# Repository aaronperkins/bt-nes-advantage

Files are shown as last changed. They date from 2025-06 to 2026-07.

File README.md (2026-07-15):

# Bluetooth NES Advantage

> ⚠️ **This repository is obsolete (v1).** The Bluetooth NES Advantage has been fully redesigned. See the current **v2** repository for the latest hardware, firmware, and docs: **https://github.com/cajunpanda/bluetooth-nes-advantage**

Integrated Bluetooth adapter for the NES Advantage (NES-026)

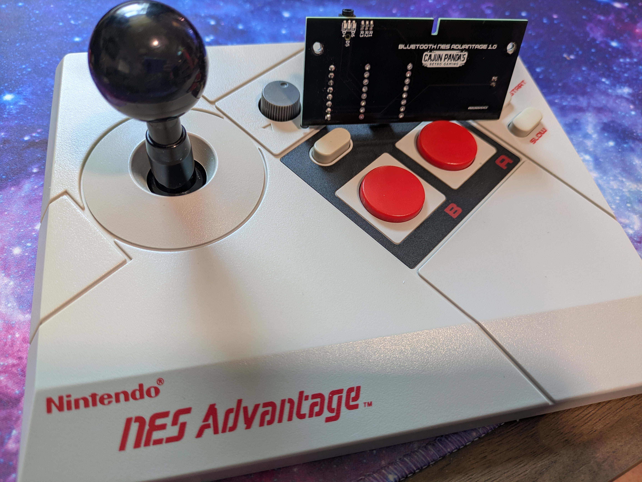
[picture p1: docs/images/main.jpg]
BT-NES-Advantage Hero Shot


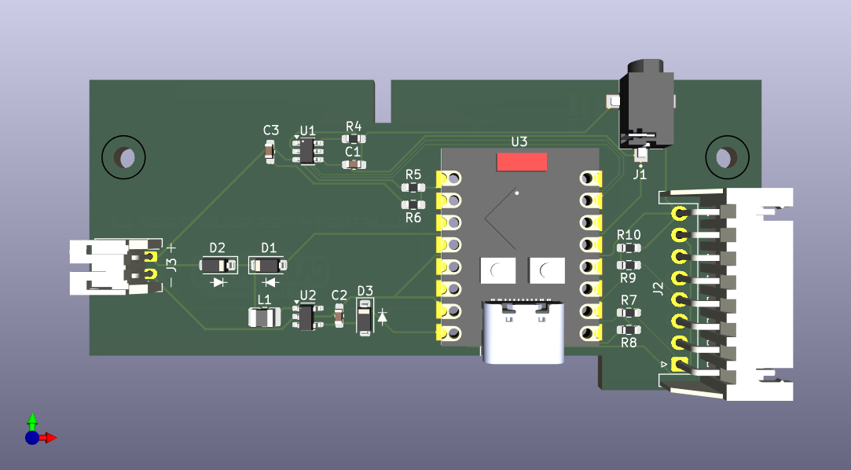
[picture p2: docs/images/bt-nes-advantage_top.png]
PCB Top


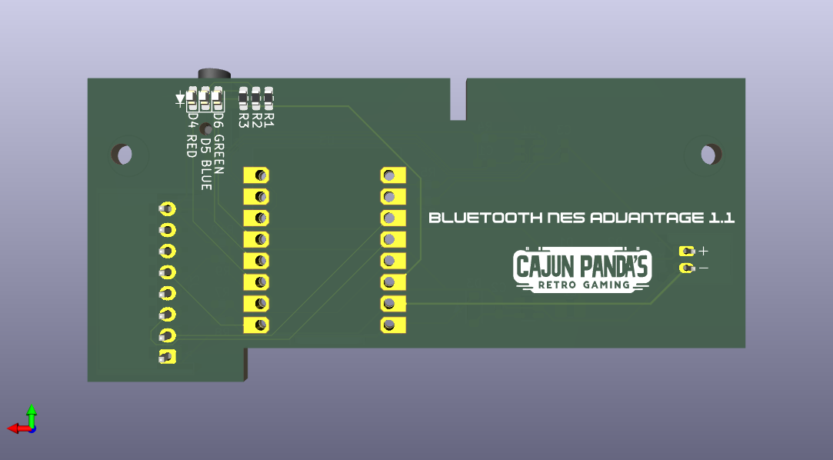
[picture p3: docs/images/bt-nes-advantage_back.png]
PCB Back


## Where to buy
Buy a completed kit ready to drop into your NES Advantage here:

[Tindie](https://www.tindie.com/products/cajunpanda/bluetooth-nes-advantage-kit/)

[Ko-Fi](https://ko-fi.com/s/c1f66f6bd5)

## Support
[Discord](https://discord.gg/t8uT8NgTnc)

## Overview
The BT-NES-Advantage is a custom Bluetooth adapter built into the NES Advantage controller, allowing it to connect wirelessly to modern devices as a standard Bluetooth gamepad. This project uses an ESP32-C3 microcontroller to read the NES controller's inputs and transmit them via Bluetooth HID protocol.

## Features
- Wireless Bluetooth LE connectivity
- Turbo and slow motion functions work as normal
- Player select switch
   - Exposes two game input devices for player 1 and 2. The player select switch redirects output to one or the other.
- Standard gamepad HID implementation, tested with:
   - BlueRetro (only works with player 1 switch)
   - Windows
   - Android
   - SteamOS
   - Linux
- *This mod does not work with the 8BitDo Retro Receiver, it doesn't support BLE*
- Long battery life with low power sleep mode
- RGB status LED indication
- Battery level monitoring and reporting
- 5V DC barrel jack charging port

## Usage Instructions

### Pairing the Controller
1. **Turn on the controller** - The controller will automatically wake up when the Start button is held.
2. **Enter pairing mode** - The controller will automatically enter pairing mode when turned on, indicated by a blinking blue LED.
3. **Pair with your device** - On your device (computer, smartphone, game console, etc.), go to Bluetooth settings and select "NES Advantage" from the list of available devices.
4. **Connection successful** - When successfully connected, the blue LED will turn solid.

### Button Mapping
The NES Advantage controller buttons are mapped to standard gamepad controls:
- **D-Pad** - Maps to the directional pad or left analog stick (configurable)
- **A button** - Maps to Button 1 (default profile) or Button 1 (Blue Retro profile)
- **B button** - Maps to Button 2 (default profile) or Button 4 (Blue Retro profile)
- **Start button** - Maps to Start button (Button 12)
- **Select button** - Maps to Select button (Button 11)

#### Button Mapping Profiles
The controller supports multiple button mapping profiles:
1. **Default Profile** - A=Button 1, B=Button 2, Select=Button 11, Start=Button 12
2. **Blue Retro Profile** - A=Button 1, B=Button 4, Select=Button 11, Start=Button 12

To change profiles, hold **A + B + Up** for 5 seconds. The red LED will blink to indicate the current profile (1 blink = Profile 1, 2 blinks = Profile 2).

#### Directional Input Modes
The controller supports three directional input modes:
1. **D-Pad Only** - Directional input sent only to the D-pad/hat switch
2. **Axes Only** - Directional input sent only to the analog stick axes
3. **Both** - Directional input sent to both D-pad and analog stick axes

To change directional modes, hold **Down + A + B** for 5 seconds. The red LED will blink to indicate the current mode (1 blink = D-Pad Only, 2 blinks = Axes Only, 3 blinks = Both).

### Special Functions
- **Sleep mode** - To manually put the controller into sleep mode, hold the **Start button** for 5 seconds. The LEDs will turn off when the controller enters sleep mode.
- **Reconnect/Pair new device** - To disconnect from the current device and enter pairing mode again, hold the **Select button** for 5 seconds.
- **Wake from sleep** - Hold the **Start button** to wake the controller from sleep mode.
- **Change button mapping profile** - Hold **A + B + Up** for 5 seconds to cycle through available button mapping profiles. The red LED will blink to indicate the current profile number.
- **Change directional pad mode** - Hold **Down + A + B** for 5 seconds to cycle through directional input modes (D-Pad Only, Axes Only, Both). The red LED will blink to indicate the current mode.

### LED Indicators
- **Blue LED**:
  - Solid ON - Connected to a device
  - Blinking - In pairing mode (advertising)
  - OFF - Not connected or in sleep mode
- **Green LED**:
  - Blinking - Battery charging
  - Solid ON - Battery fully charged
  - OFF - Not charging
- **Red LED**:
  - Blinking - Low battery (below 20%)
  - OFF - Battery level normal

### Battery and Power
- The controller uses a rechargeable LiPo battery.
- To charge, connect a 5V DC power adapter to the barrel jack.
- Battery level is reported to the connected device when supported.
- The controller will automatically enter sleep mode after 5 minutes of inactivity to conserve power.
- When advertising (pairing mode), the controller will stop advertising after 30 seconds to save battery.

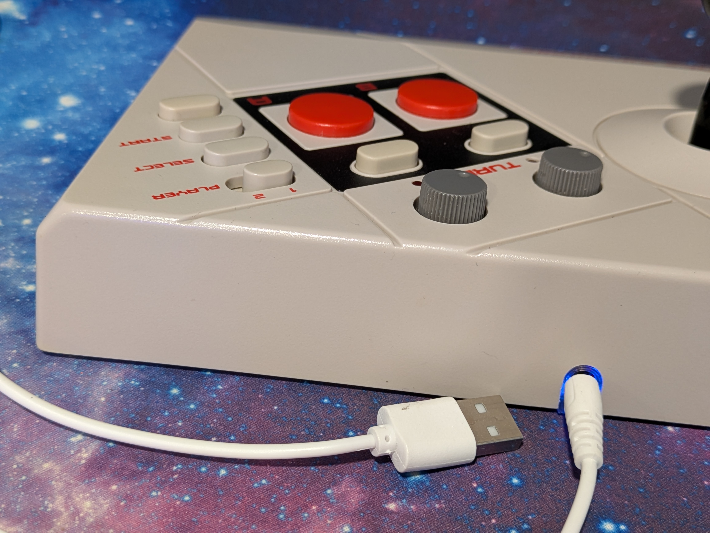
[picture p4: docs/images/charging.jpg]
Controller Charging

*NES Advantage controller charging via 5V DC barrel jack*

### 3D Printable DC Jack Plug

For a clean installation, a custom 3D printable DC jack plug is available that fits perfectly in the NES Advantage case:

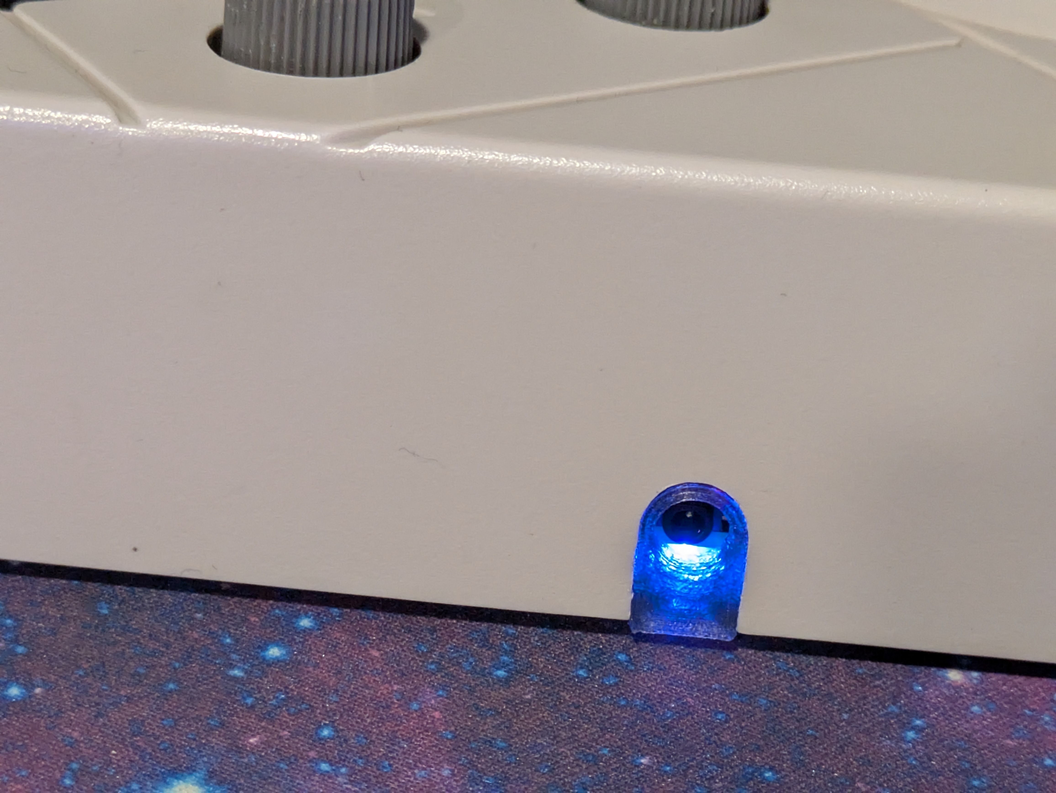
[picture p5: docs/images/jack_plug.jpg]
DC Jack Plug

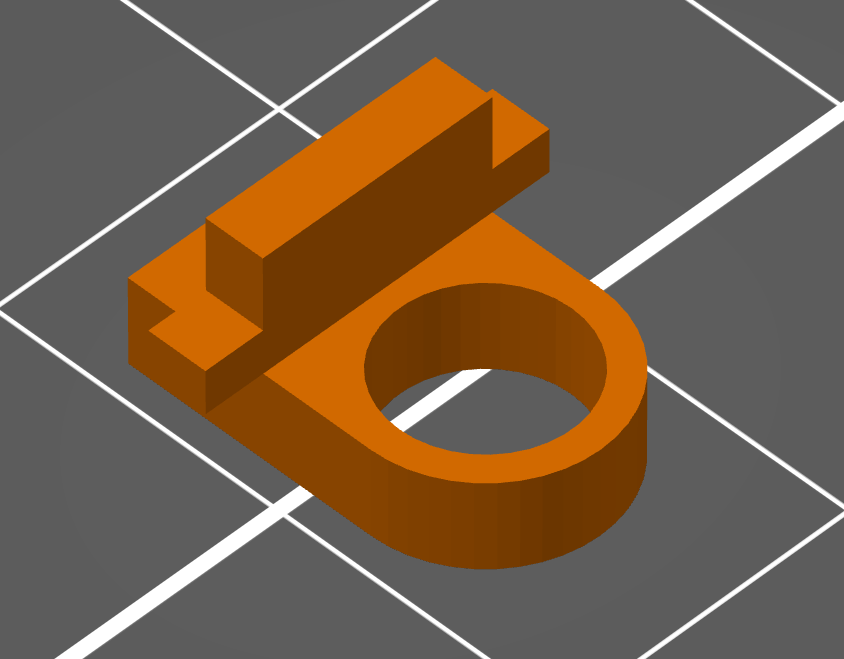
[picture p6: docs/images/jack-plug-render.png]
DC Jack Plug Render


**Download STL file**: [bt_nes_advantage-jack_plug.stl](models/bt_nes_advantage-jack_plug.stl)

Print with a transparent PLA in order to see the status LEDs.

### Troubleshooting
- If unable to pair with a new device, ensure the controller is in pairing mode (blue LED blinking).

## Technical Specifications
- MCU: ESP32-C3 (LOLIN C3 Mini)
- Bluetooth: BLE 5.0
- Battery: 3.7V LiPo 
- Charging: Via 5V DC barrel jack
- Power consumption: ~120mA when connected, <1mA in sleep mode
- Original NES controller compatibility: 100% hardware compatible

## PCB Assembly Instructions
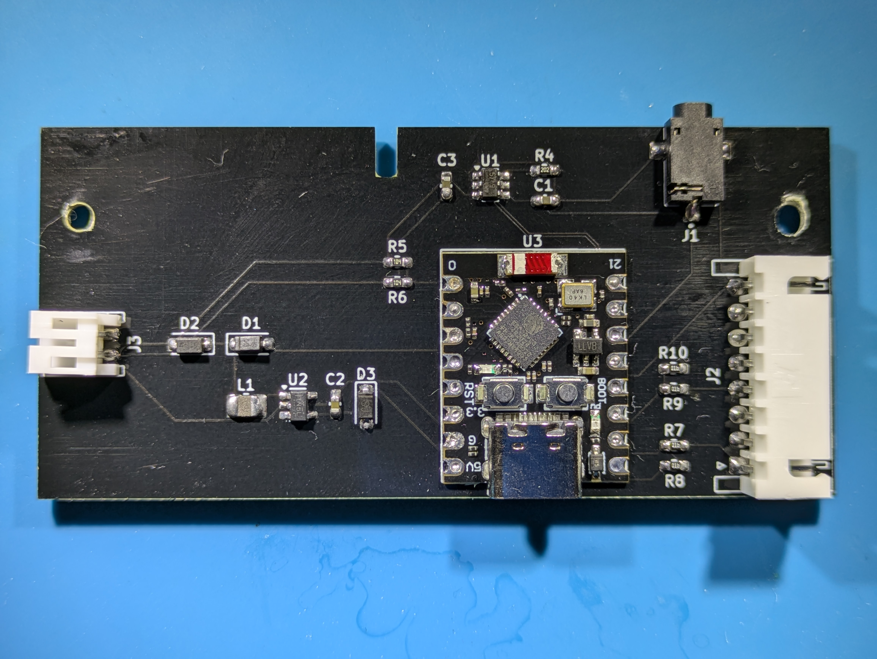
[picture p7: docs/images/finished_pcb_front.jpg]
Finished PCB

### Bill of Materials (BOM)

| Designator | Qty | Value | Footprint | Description | Notes |
|---|-----|---|---|---|---|
| C1, C3 | 2 | 10µF | C_0603_1608Metric | Unpolarized capacitor | SMT |
| C2 | 1 | 22µF | C_0603_1608Metric | Unpolarized capacitor | SMT |
| D1, D2, D3 | 3 | 1N5817W | D_SOD-123 | Schottky diode | SMT |
| D4, D5, D6 | 3 | LED | LED_0603_1608Metric | RGB LED (R,G,B) | SMT, 1=K 2=A |
| J1 | 1 | PJ-043-SMT-TR | CUI_PJ-040-SMT-TR | DC Power Jack | SMT, 5V input |
| J2 | 1 | Conn_01x08_Socket | JST_XH_S8B-XH-A_1x08_P2.50mm | 8-pin NES controller connector | Horizontal, THT |
| J3 | 1 | JST Connector | JST_PH_S2B-PH-K_1x02_P2.00mm | LiPo battery connector | Horizontal, THT |
| L1 | 1 | 2.2µH | L_1008_2520Metric | Inductor | SMT |
| R1, R2, R3 | 3 | 200Ω | R_0603_1608Metric | Resistor for LEDs | SMT |
| R7, R8, R9, R10 | 4 | 1KΩ | R_0603_1608Metric | Resistor | SMT |
| R4 | 1 | 2KΩ | R_0603_1608Metric | Resistor | SMT |
| R5, R6 | 2 | 100KΩ | R_0603_1608Metric | Voltage divider for battery monitoring | SMT |
| U1 | 1 | TP4057 | TSOT-23-6 | Li-ion battery charger IC | SMT |
| U2 | 1 | TPS613222ADBV | SOT-23-5 | 5V boost converter | SMT |
| U3 | 1 | ESP32-C3_SUPERMINI_TH | ESP32-C3 SuperMini | ESP32-C3 WiFi/BLE module | THT |

### Parts Sourcing

- **PCB**: [PCBWay Project - Order PCB](https://www.pcbway.com/project/shareproject/Bluetooth_NES_Advantage_865d24ef.html)
- **Parts List**: [Digikey Parts List](https://www.digikey.com/en/mylists/list/EVZPX74W7P)
- **ESP32-C3 SuperMini Module**: [Amazon Link](https://a.co/d/1LoWyFs)
- **J2 Connector Harness Cable**: [Amazon Link](https://a.co/d/abYfjqw)
- **Recommended Battery**: [103450 3.7V LiPo Battery](https://a.co/d/7UFYwX9) (IMPORTANT: Check polarity before connecting)
- **Charging cable**: [DC 2.5x0.7mm Barrel Jack Power Cable](https://a.co/d/4bPUQj2)

### Schematic
[Link to PDF](docs/schematic.pdf)

### Gerber
[Link to Gerber files](pcb/bt-nes-advantage.kicad_pcb.zip)

### Assembly Steps
1. **PCB Preparation**
   - Ensure you have the latest PCB design files from the `pcb` directory
   - Verify that all components from the BOM are available before starting

2. **Component Placement Order**
   - Start with SMD components in this order:
     1. Resistors (R1-R10)
     2. Capacitors (C1-C3)
     3. Diodes (D1-D3)
     4. LEDs (D4-D6) - Note the polarity! Cathode (K) is marked
     5. ICs (U1, U2)
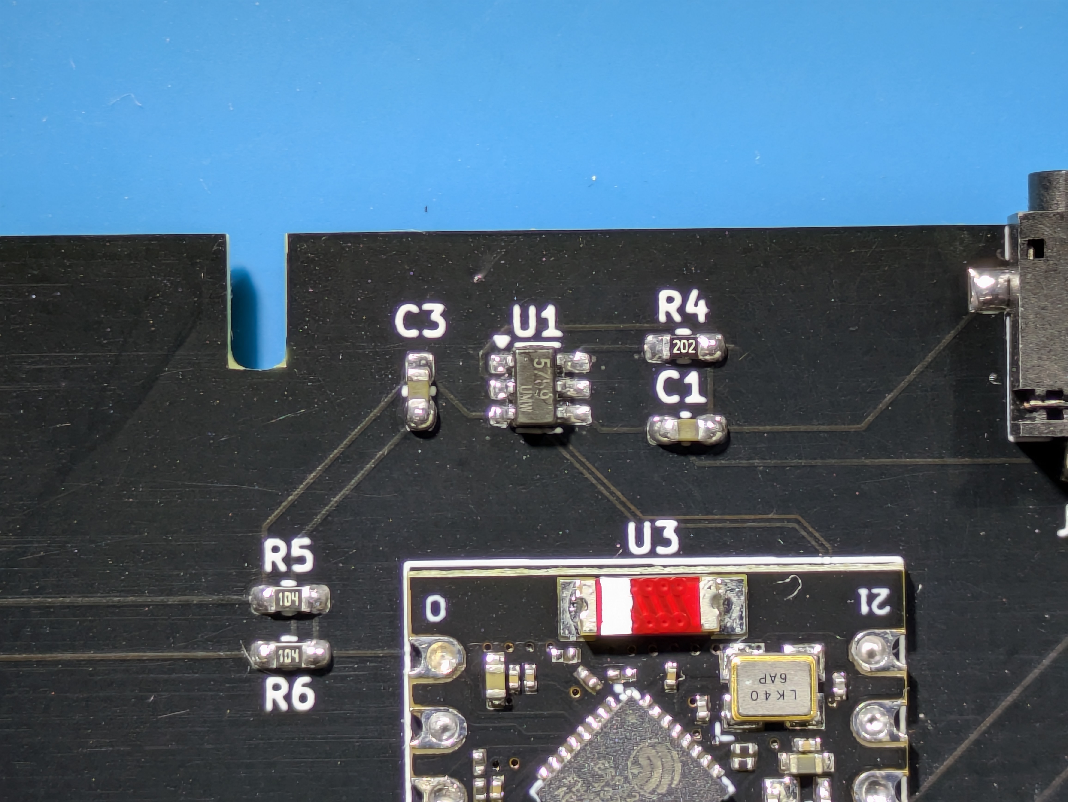
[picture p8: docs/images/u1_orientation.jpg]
U1 Orientation
     
*TP4057 U1 pin 1 may not be marked, make sure to get the orientation right by referencing this image and the datasheet.*
     6. Inductor (L1)
     7. DC Jack (J1)
   - Then place through-hole components:
     1. JST connectors (J2, J3)
     2. ESP32-C3 module (U3)

3. **Soldering Guidelines**
   - For SMD components:
     - Use a fine-tip soldering iron (0.5mm or smaller)
     - Recommended temperature: 320-350°C
     - Apply small amount of flux for better results
     - Use tweezers for precise placement
   - For THT components:
     - Secure components flush to PCB before soldering
     - Solder from the lowest-profile components to the highest

4. **Power Connections**
   - The battery connector (J3) is for a 3.7V LiPo battery
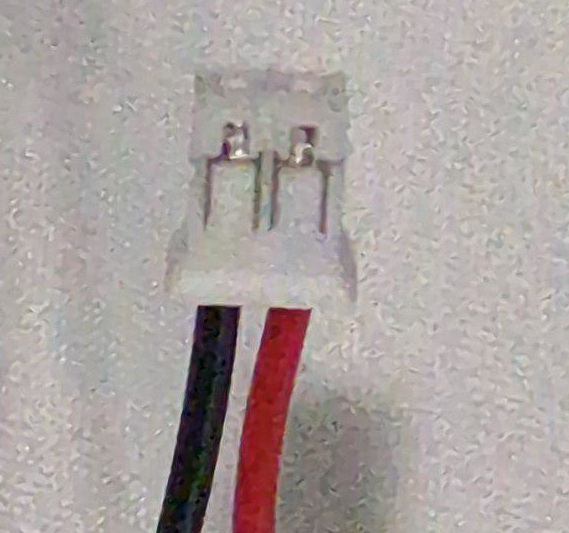
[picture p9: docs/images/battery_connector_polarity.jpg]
Battery Connector Polarity
     
*Check your battery polarity! There isn't a standard and it may be swapped from what is required!*   
   - Use appropriate JST PH connector with correct polarity
   - The power jack (J1) accepts 5V DC input

5. **Controller Connections**
   - Connect the PCB to the NES Advantage controller using the 8-pin JST XH connector (J2)
   - Pinout from left to right: DATA_P1, LATCH, CLK_P1, DATA_P2, CLK_P2, N/C, +5V, GND
    6. **Pin Mapping**
        - Refer to this pin mapping diagram for connecting the PCB to the NES Advantage controller:
        
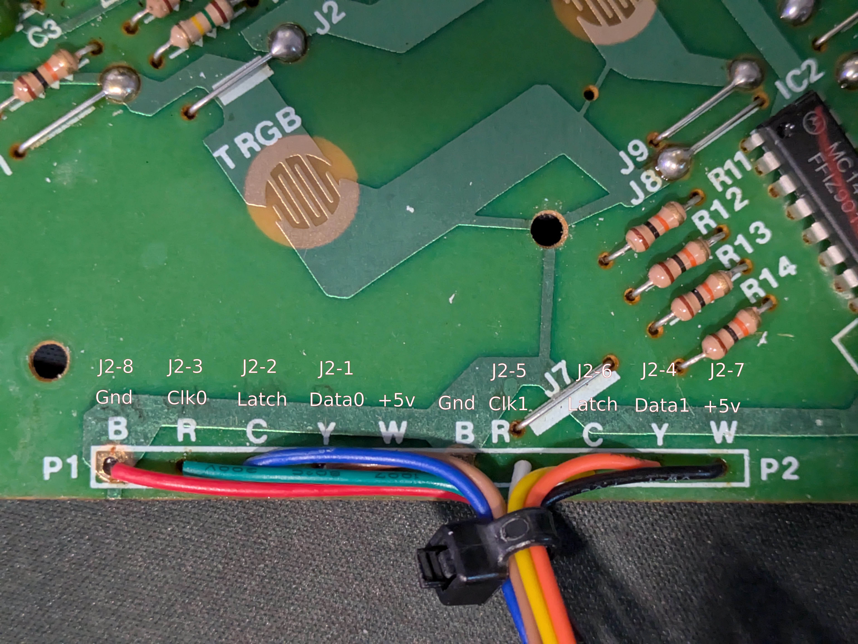
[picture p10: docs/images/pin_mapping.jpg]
NES Advantage Pin Mapping
        
        
7. **Installation in Controller**
    - Carefully open the NES Advantage controller by removing the screws from the bottom. Refer to this video for a full teardown:
    
    NES Advantage Clean & Teardown (https://youtu.be/Sw1IDFrGwic?si=m9LdfxoDmvacOw2x)

    - Install the battery in the recommended position:
    
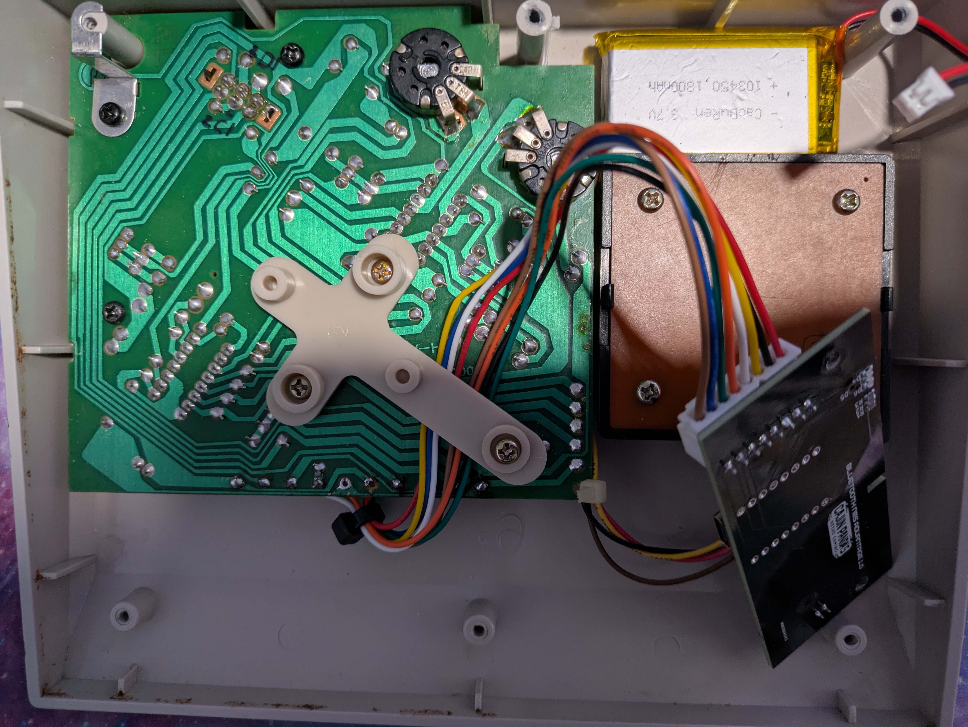
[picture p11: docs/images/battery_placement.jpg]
Battery Placement
    
    
    - Place the PCB in the controller as shown below:
    
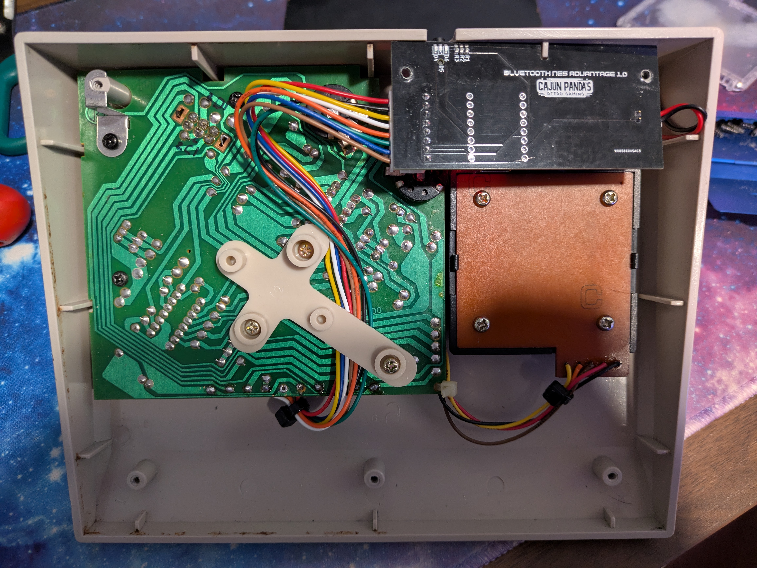
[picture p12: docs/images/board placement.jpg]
PCB Placement
    
    
    - Route wires to avoid interference with moving parts of the joystick

    - Finally add some insulating tape to the metal back cover to avoid accidental shorting when reassembling.
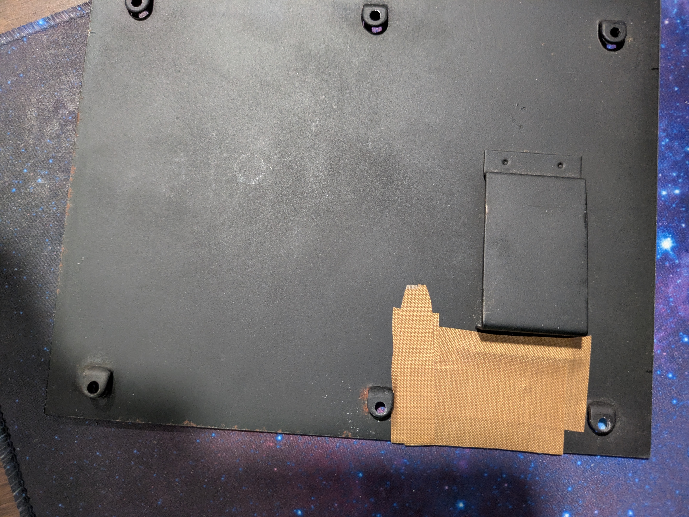
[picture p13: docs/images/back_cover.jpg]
Back Cover Tape
    

## Firmware Instructions

### Option 1: Using Prebuilt Firmware (Recommended)

1. **Download the Firmware**
   - Go to the [Releases page](https://github.com/aaronperkins/bt-nes-advantage/releases) on GitHub
   - Download the latest firmware release

2. **Install ESP Flash Tool**
   - For Linux/Mac: Install `esptool` via pip:
     ```bash
     pip install esptool
     ```
   - For Windows: Download the [ESP Flash Download Tool](https://www.espressif.com/en/support/download/other-tools) from Espressif

3. **Connect the ESP32-C3 SuperMini**
   - Connect the ESP32-C3 SuperMini module to your computer via USB
   - Put the device in download mode by holding the BOOT button while connecting

4. **Flash the Firmware**
   
   #### Option A: Single Merged Binary (Easiest)
   If a merged binary file (`bt_nes_advantage_lolin_c3_mini.bin`) is available:
   ```bash
   esptool.py --chip esp32c3 write_flash 0x0 bt_nes_advantage_lolin_c3_mini.bin
   ```
   
   #### Option B: Individual Binary Files
   If using separate `bootloader.bin`, `partitions.bin`, and `firmware.bin` files:
   - For Linux/Mac (using esptool):
     ```bash
     esptool.py --chip esp32c3 write_flash 0x0000 bootloader.bin 0x8000 partitions.bin 0x10000 firmware.bin
     ```
   - For Windows (using ESP Flash Download Tool):
     - Select Chip Type: ESP32-C3
     - Select bootloader.bin at address 0x0000
     - Select partitions.bin at address 0x8000
     - Select firmware.bin at address 0x10000
     - Select the correct COM port
     - Click "START" to begin flashing

5. **Verify Installation**
   - After flashing completes, press the RST button or disconnect and reconnect the device
   - The blue LED should start blinking indicating pairing mode

### Option 2: Building and Uploading from Source

#### Prerequisites
- VSCode
- PlatformIO VSCode extention
- USB cable for connecting to the ESP32-C3 SuperMini module

#### Building the Firmware with PlatformIO

1. **Install PlatformIO**
   - Install PlatformIO as an extension for VSCode

2. **Clone the Repository**
   ```bash
   git clone https://github.com/aaronperkins/bt-nes-advantage.git
   cd bt-nes-advantage
   ```

3. **Open the Project in PlatformIO**
   - In VSCode with PlatformIO extension, select "Open Project" and choose the `firmware` folder

4. **Configure the Project**
   - The `platformio.ini` file is already configured with the correct settings

5. **Build the Project**
   - In PlatformIO IDE, click on the "Build" button

6. **Connect the ESP32-C3 SuperMini**
   - Connect the ESP32-C3 SuperMini module to your computer via USB
   - If you've already installed it in the controller, you'll need to either:
     - Connect to the USB port on the module

7. **Upload the Firmware**
   - In PlatformIO IDE, click on the "Upload" button

8. **Create Distribution Files (Optional)**
   - If using VS Code with the included tasks, you can create merged firmware files for distribution:
     - Press `Ctrl+Shift+P` and select "Tasks: Run Task"
     - Choose "Full Release Build" to create optimized firmware with merged binary
     - Or choose "Build and Upload Release" to build and upload in one step
     - Distribution files will be created in the `dist/` folder

9. **Monitor Serial Output (Optional)**
   - For debugging, you can monitor the serial output at 115200 baud
   - In PlatformIO IDE, click on the "Serial Monitor" button

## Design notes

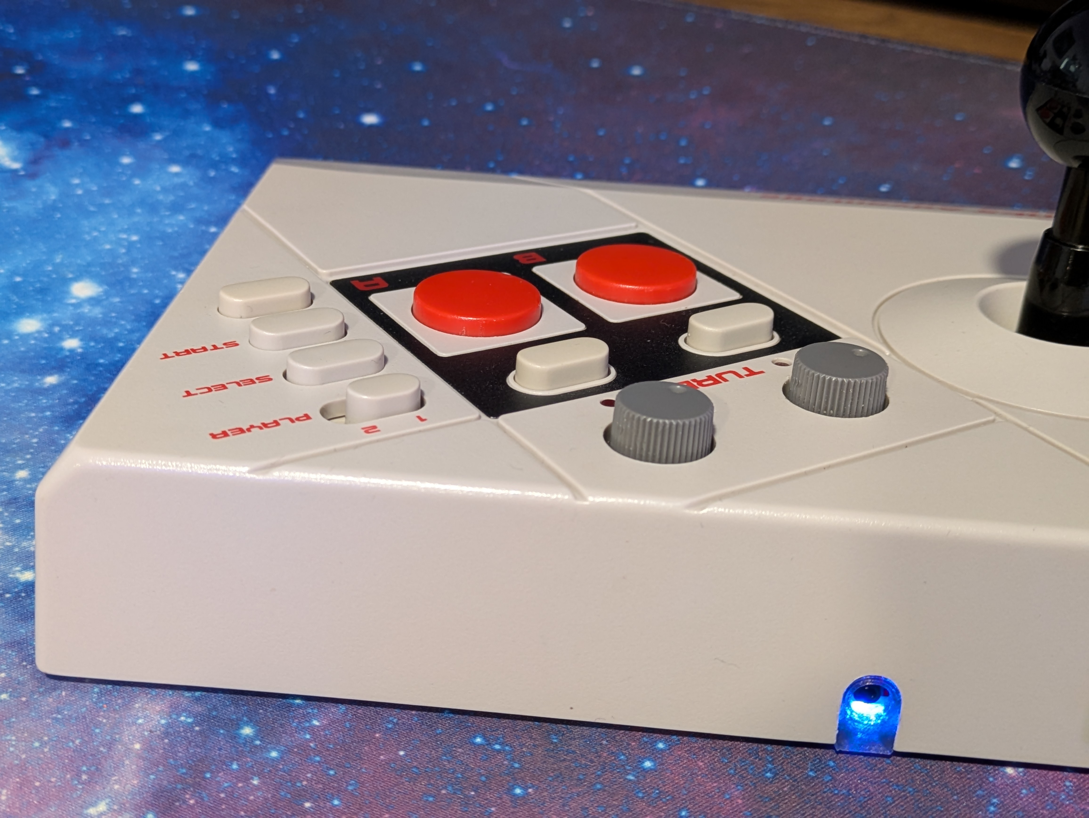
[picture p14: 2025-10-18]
docs/images/rear_shot.jpg

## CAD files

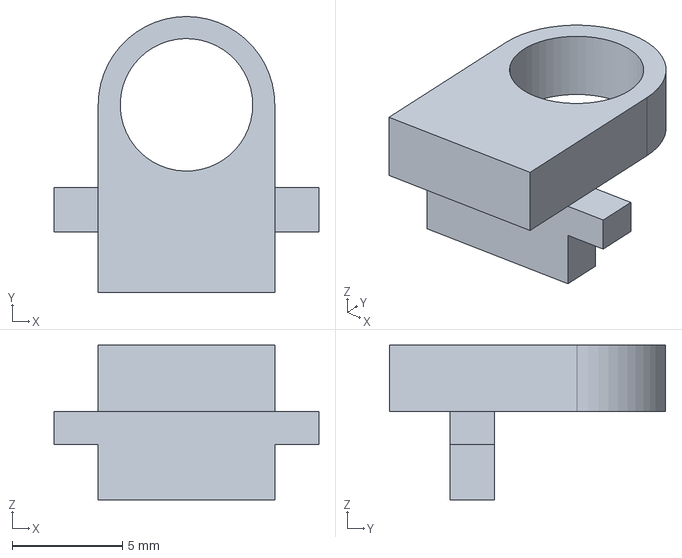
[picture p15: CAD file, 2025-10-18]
models/bt_nes_advantage.FCStd
12.0 x 12.5 x 7.00 mm

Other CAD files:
models/bt_nes_advantage-jack_plug.stl

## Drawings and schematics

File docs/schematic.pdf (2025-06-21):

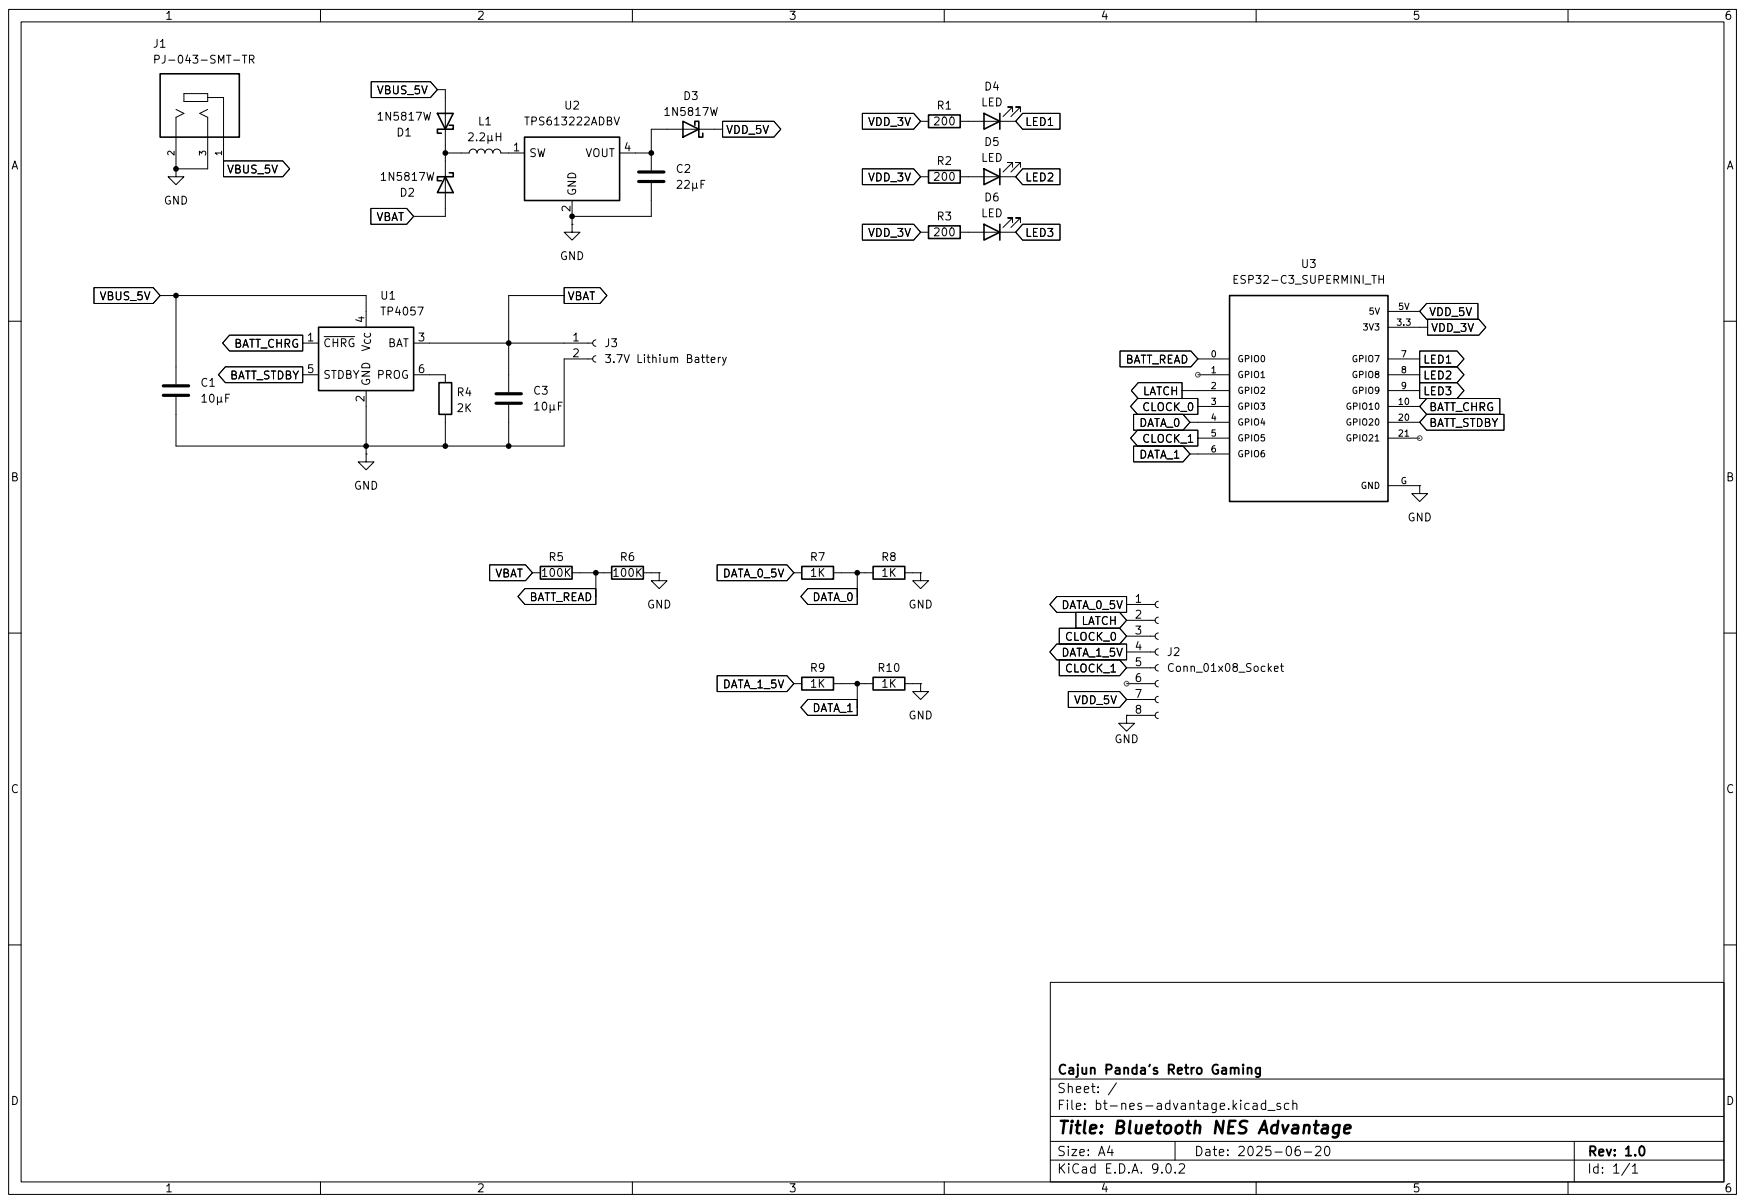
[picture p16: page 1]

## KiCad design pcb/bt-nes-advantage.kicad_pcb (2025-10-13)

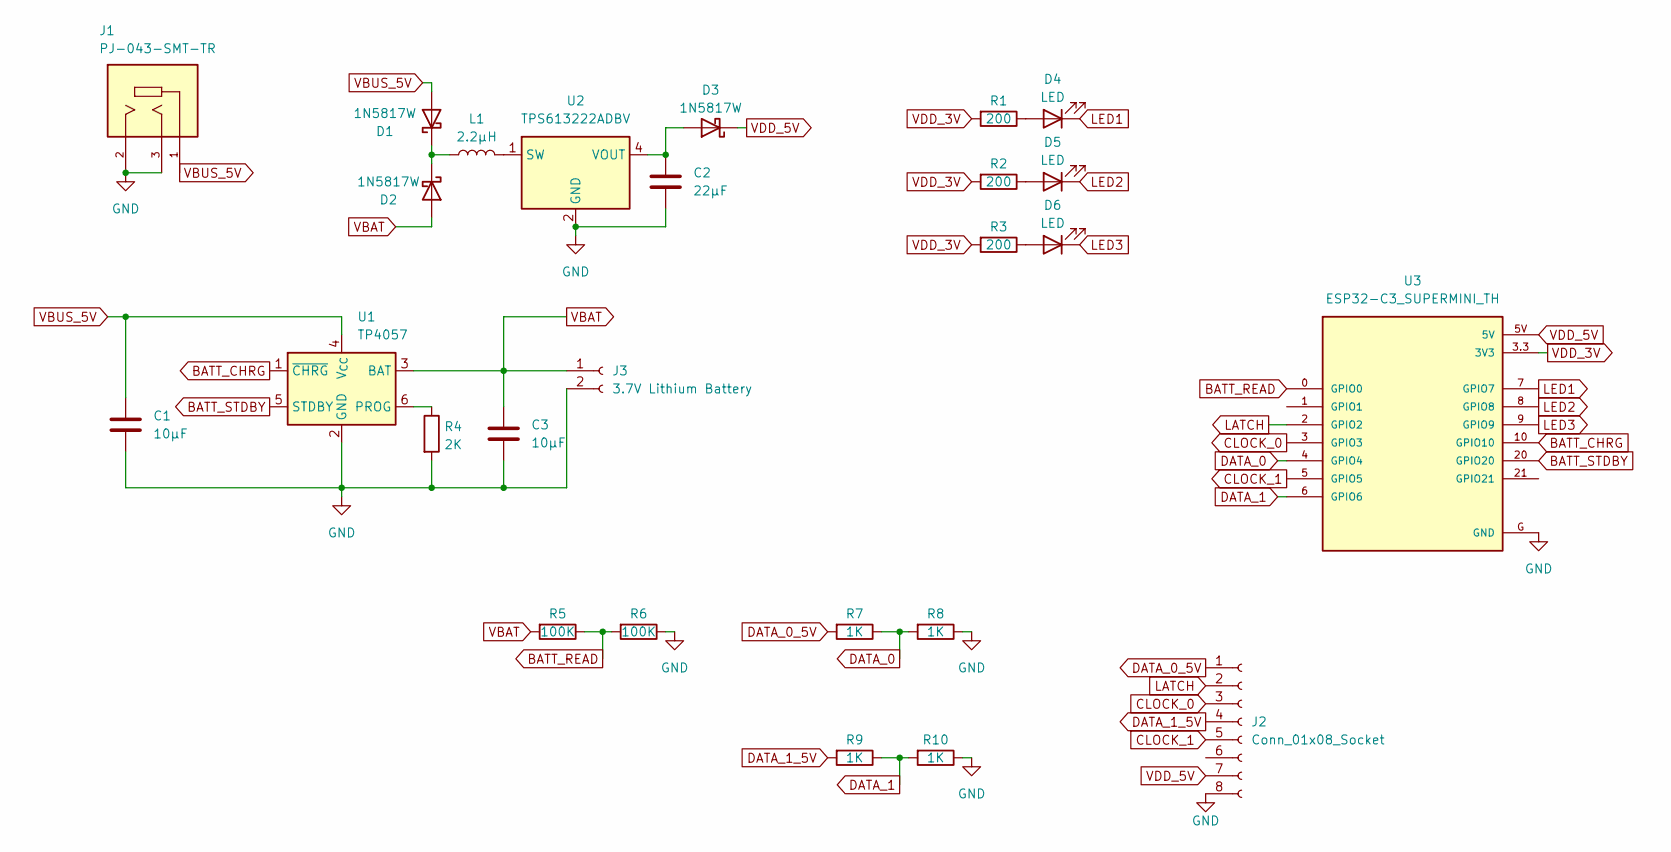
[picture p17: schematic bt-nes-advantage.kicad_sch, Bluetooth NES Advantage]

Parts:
C1, C3: 10µF; C_0603_1608Metric_Pad1.08x0.95mm_HandSolder
C2: 22µF; C_0603_1608Metric_Pad1.08x0.95mm_HandSolder
D1, D2, D3: 1N5817W; D_SOD-123
D4, D5, D6: LED; LED_0603_1608Metric_Pad1.05x0.95mm_HandSolder
J1: PJ-043-SMT-TR; CUI_PJ-040-SMT-TR; Mouser Part Number 490-PJ-043-SMT-TR
J2: Conn_01x08_Socket; JST_XH_S8B-XH-A_1x08_P2.50mm_Horizontal
J3: 3.7V Lithium Battery; JST_PH_S2B-PH-K_1x02_P2.00mm_Horizontal
L1: 2.2µH; L_1008_2520Metric_Pad1.43x2.20mm_HandSolder
R1, R2, R3: 200; R_0603_1608Metric_Pad0.98x0.95mm_HandSolder
R4: 2K; R_0603_1608Metric_Pad0.98x0.95mm_HandSolder
R5, R6: 100K; R_0603_1608Metric_Pad0.98x0.95mm_HandSolder
R7, R8, R9, R10: 1K; R_0603_1608Metric_Pad0.98x0.95mm_HandSolder
U1: TP4057; TSOT-23-6
U2: TPS613222ADBV; SOT-23-5
U3: ESP32-C3_SUPERMINI_TH; MODULE_ESP32-C3_SUPERMINI

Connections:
BATT_CHRG: U1.1 (~CHRG), U3.10 (GPIO10)
BATT_READ: R5.1, R6.2, U3.0 (GPIO0)
BATT_STDBY: U1.5 (STDBY), U3.20 (GPIO20)
CLOCK_0: J2.3, U3.3 (GPIO3)
CLOCK_1: J2.5, U3.5 (GPIO5)
DATA_0: R7.1, R8.2, U3.4 (GPIO4)
DATA_0_5V: J2.1, R7.2
DATA_1: R9.1, R10.2, U3.6 (GPIO6)
DATA_1_5V: J2.4, R9.2
GND: C1.2, C2.2, C3.2, J1.2, J1.3, J2.8, J3.2, R4.2, R6.1, R8.1, R10.1, U1.2 (GND), U2.2 (GND), U3.G (GND)
LATCH: J2.2, U3.2 (GPIO2)
LED1: D4.1 (K), U3.7 (GPIO7)
LED2: D5.1 (K), U3.8 (GPIO8)
LED3: D6.1 (K), U3.9 (GPIO9)
unnamed: D1.1 (K), D2.1 (K), L1.1
unnamed: C2.1, D3.2 (A), U2.4 (VOUT)
unnamed: D4.2 (A), R1.1
unnamed: D5.2 (A), R2.1
unnamed: D6.2 (A), R3.1
unnamed: R4.1, U1.6 (PROG)
unnamed: L1.2, U2.1 (SW)
VBAT: C3.1, D2.2 (A), J3.1, R5.2, U1.3 (BAT)
VBUS_5V: C1.1, D1.2 (A), J1.1, U1.4 (V_{CC})
VDD_3V: R1.2, R2.2, R3.2, U3.3.3 (3V3)
VDD_5V: D3.1 (K), J2.7, U3.5V

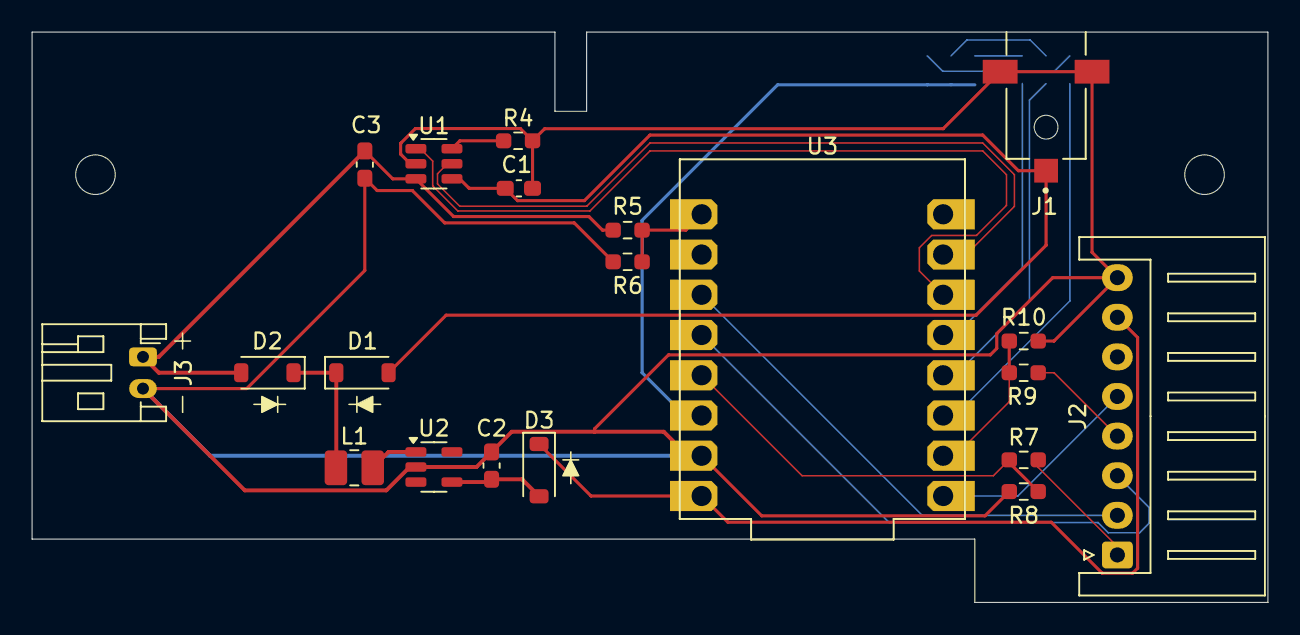
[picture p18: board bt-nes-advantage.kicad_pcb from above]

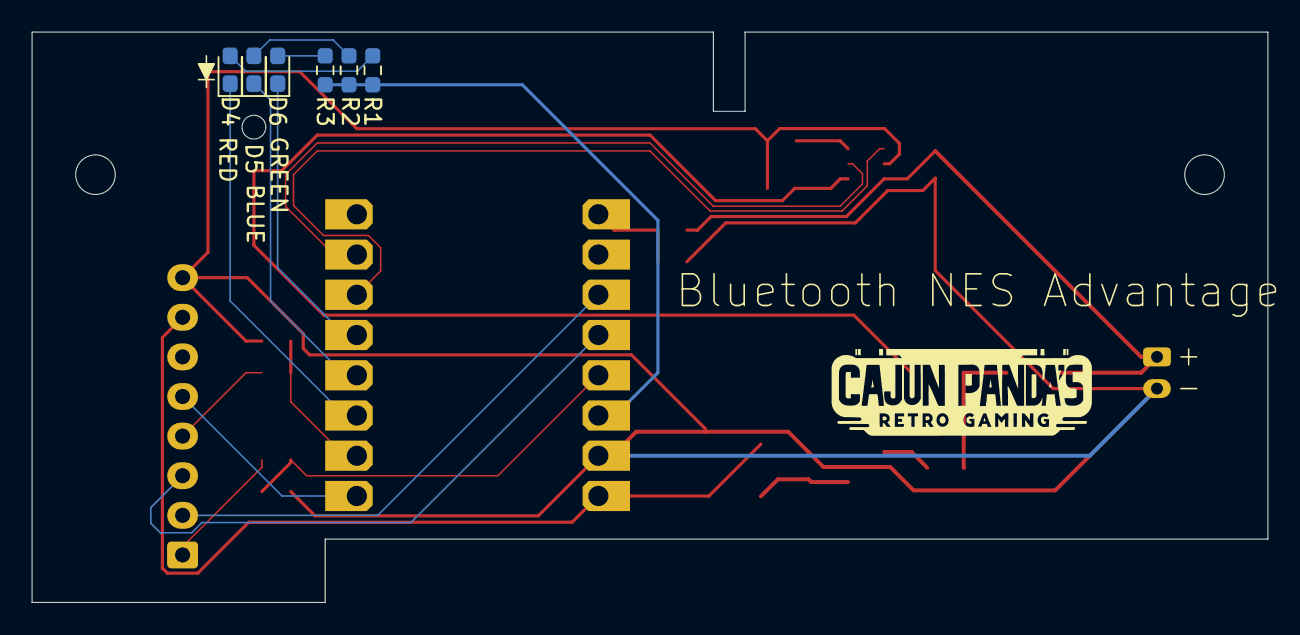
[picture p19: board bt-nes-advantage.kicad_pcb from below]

Board: 2 copper layers, 78.0 x 36.0 mm, 26 parts (6 on the bottom side), 25 nets.

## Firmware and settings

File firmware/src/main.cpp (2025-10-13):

// Bluetooth HID NES Advantage Joystick
// Copyright (C) 2025 Aaron Perkins
//
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
#include <Arduino.h>
#include "BLEJoystick.h"
#include "NESController.h"
#include <Preferences.h>

#define BATTERY_PIN 0
#define BATTERY_VOLTAGE_DIVIDER_R1 100000         // 100k ohm (nominal)
#define BATTERY_VOLTAGE_DIVIDER_R2 100000         // 100k ohm (nominal)
#define BATTERY_VOLTAGE_CALIBRATION_FACTOR 0.928  // Adjust this factor for calibration
#define BATTERY_MIN_VOLTAGE 3.00                  // Minimum battery voltage (in volts)
#define BATTERY_MAX_VOLTAGE 4.20                  // Maximum battery voltage (in volts)
#define BATTERY_SMOOTHING_FACTOR 0.1              // Smoothing factor for EMA (0.0-1.0, lower means more smoothing)
#define BATTERY_SAMPLES 5                         // Number of samples to average for initial reading
#define RED_LED_PIN 7
#define BLUE_LED_PIN 8
#define GREEN_LED_PIN 9
#define BATTERY_CHARGE_PIN 10
#define BATTERY_STANDBY_PIN 20

// NES Pin Mapping
#define CLK_PIN_P1 3
#define CLK_PIN_P2 5
#define LATCH_PIN 2
#define DATA_PIN_P1 4
#define DATA_PIN_P2 6

// Timing constants
#define SLEEP_CYCLE_TIME 5000000        // How long the controller sleeps before waking to check input (microseconds)
#define BATTERY_POLL_TIME 1000          // How often to poll battery status (milliseconds)
#define CONNECTION_IDLE_TIMEOUT 60000   // How long the controller remain unconnected before going to sleep (milliseconds)
#define IDLE_TIMEOUT 300000             // How long the controller remains idle (no buttons presses) before going to sleep (milliseconds)
#define ADVERTISING_TIMEOUT 30000       // How long the controller advertises before giving up (milliseconds)
#define POWER_OFF_HOLD_TIME 5000        // How long the start button must be held to power off (milliseconds)
#define RECONNECT_HOLD_TIME 5000        // How long the select button must be held to reconnect (milliseconds)
#define PROFILE_CHANGE_HOLD_TIME 5000   // How long A+B+Up must be held to change profile (milliseconds)
#define DPAD_MODE_CHANGE_HOLD_TIME 5000 // How long Down+A+B must be held to change dpad mode (milliseconds)

// Directional input modes
enum DirectionalMode {
  DPAD_ONLY = 0,    // Send directional input to dpad only
  AXES_ONLY = 1,    // Send directional input to axes only  
  BOTH = 2          // Send directional input to both dpad and axes
};

const char* directionalModeNames[] = {
  "D-Pad Only",
  "Axes Only", 
  "Both"
};

const uint8_t NUM_DIRECTIONAL_MODES = sizeof(directionalModeNames) / sizeof(directionalModeNames[0]);

// Button mapping profiles
struct ButtonProfile {
  const char* name;
  uint8_t buttonA;      // Joystick button for NES A
  uint8_t buttonB;      // Joystick button for NES B
  uint8_t buttonSelect; // Joystick button for NES SELECT
  uint8_t buttonStart;  // Joystick button for NES START
};

// Define available profiles
const ButtonProfile profiles[] = {
  {"Default", 1, 2, 11, 12},      // Profile 1: Default mapping
  {"Blue Retro", 1, 4, 11, 12}   // Profile 2: Blue Retro mapping
};

const uint8_t NUM_PROFILES = sizeof(profiles) / sizeof(profiles[0]);

// Global state
BLEJoystick* joystick;
NESController* nesController;
Preferences preferences;
int playerSelection = 0; // 0 for P1, 1 for P2
uint8_t currentProfile = 0; // Current button mapping profile
DirectionalMode currentDirectionalMode = DPAD_ONLY; // Current directional input mode
unsigned int batteryLevel = 0;
float batteryVoltage = 0.0;
float smoothedBatteryVoltage = 0.0;
bool isBatteryCharging = false;
bool isBatteryStandBy = false;
bool isExternalPower = false;
unsigned long idleStartTime = 0;
unsigned long advertisingStartTime = 0;
unsigned long lastBatteryCheck = 0;
unsigned long startButtonPressTime = 0;
unsigned long selectButtonPressTime = 0;
unsigned long profileChangeStartTime = 0;
unsigned long dpadModeChangeStartTime = 0;
RTC_DATA_ATTR bool sleeping = false;

// Function prototypes
void joystickStateCallback();
void playerSelectionCallback(uint8_t newPlayer);
void loadProfile();
void saveProfile();
void changeProfile();
void blinkIndicator(uint8_t profile, uint8_t count);
void loadDirectionalMode();
void saveDirectionalMode();
void changeDirectionalMode();
void updateJoystickDirectional(uint8_t player);
void updateJoystickButtons(uint8_t player);
bool readBatteryState();
void checkTimers();
void enterSleepMode();
void reportControllerState();

void setup() {
  // Initialize preferences for persistent storage
  preferences.begin("nes-advantage", false);
  
  // Initialize NES controller
  nesController = new NESController(CLK_PIN_P1, CLK_PIN_P2, LATCH_PIN, DATA_PIN_P1, DATA_PIN_P2);
  nesController->begin();
  nesController->read();
  playerSelection = nesController->getPlayerSelection();
  
  // Initialize battery state
  pinMode(BATTERY_CHARGE_PIN, INPUT_PULLUP);
  pinMode(BATTERY_STANDBY_PIN, INPUT_PULLUP);
  readBatteryState();

  // If sleeping, keep sleeping until the start button is held or battery is charging
  if (sleeping) {
    if (nesController->getButtonState(playerSelection, NESController::BUTTON_START)
          || isExternalPower) {
      sleeping = false;
    }
    else {
      enterSleepMode();   
    }
  }

  // Initialize serial for debugging
  Serial.begin(9600);

  // Set up NES controller player selection callback
  nesController->setPlayerSelectionCallback(playerSelectionCallback);

  // Configure LED pins
  pinMode(RED_LED_PIN, OUTPUT);
  pinMode(GREEN_LED_PIN, OUTPUT);
  pinMode(BLUE_LED_PIN, OUTPUT);
  digitalWrite(RED_LED_PIN, HIGH);
  digitalWrite(GREEN_LED_PIN, HIGH);
  digitalWrite(BLUE_LED_PIN, HIGH);

  // Load saved profile
  loadProfile();
  
  // Load saved directional mode
  loadDirectionalMode();
    
  // Initialize timers
  idleStartTime = millis();
  advertisingStartTime = millis();
  lastBatteryCheck = millis();

  // Initialize the BLE joystick and begin advertising
  joystick = new BLEJoystick("NES Advantage", "Cajun Panda's Retro Gaming", 0x42CA, 0x42CD, 2);
  joystick->setStateChangeCallback(joystickStateCallback);
  joystick->start();
  joystick->startAdvertising();
}

void loop() {
  nesController->read();
 
  // Update joystick if state changed for either player
  bool anyStateChanged = nesController->stateChanged(0) || nesController->stateChanged(1);
  
  if (anyStateChanged) {

    reportControllerState();

    // If connected, update BLE Joystick state
    if (joystick->getState() == BLEJoystick::DEVICE_CONNECTED) {
      
      // Update joystick state based on current player selection
      updateJoystickDirectional(playerSelection);
      updateJoystickButtons(playerSelection);
      joystick->notifyPlayerHIDReport(playerSelection);
      
    // else begin advertising
    } else if (joystick->getState() == BLEJoystick::DEVICE_IDLE 
                && selectButtonPressTime == 0) {
      joystick->startAdvertising();
    }
  }
      
  checkTimers();
}

void reportControllerState()
{
  // Report both players
  for (int player = 0; player < 2; player++) {
    Serial.print("NES State P");
    Serial.print(player + 1);
    Serial.print(": ");
    for (int i = 0; i < 8; i++)
    {
      Serial.print(nesController->getButtonState(player, i) ? "1" : "0");
    }
    Serial.println();
  }
}

void joystickStateCallback() {
  switch (joystick->getState()) {
    case BLEJoystick::DEVICE_IDLE:
      Serial.println("Device idle.");
      digitalWrite(BLUE_LED_PIN, HIGH);
      idleStartTime = millis();
      break;
      
    case BLEJoystick::DEVICE_ADVERTISING:
      Serial.println("Device advertising.");
      advertisingStartTime = millis();
      break;
      
    case BLEJoystick::DEVICE_CONNECTED:
      Serial.println("Device connected.");
      digitalWrite(BLUE_LED_PIN, LOW);
      // Send initial battery level
      joystick->setBatteryLevel(batteryLevel);
      joystick->notifyBatteryLevel();
      break;
      
    default:
      break;
  }
}

void playerSelectionCallback(uint8_t newPlayer) {
  // Clear previous player state
  joystick->setPlayerButtons(playerSelection,
    false, false, false, false,
    false, false, false, false,
    false, false, false, false
  );
  joystick->setPlayerHat(playerSelection, 0);
  joystick->setPlayerAxes(playerSelection, 0, 0, 0, 0, 0, 0, 0, 0);
  joystick->notifyPlayerHIDReport(playerSelection);

  // set new player selection
  playerSelection = newPlayer;
  Serial.print("Player selection changed to P");
  Serial.println(playerSelection + 1);
}

void checkTimers() {
  unsigned long currentTime = millis();
  
  // Check battery state periodically
  if (currentTime - lastBatteryCheck > BATTERY_POLL_TIME) {
    if (readBatteryState()) {
      Serial.print("Battery level: ");
      Serial.print(batteryLevel);
      Serial.print("% - Battery voltage: ");
      Serial.print(batteryVoltage, 3);
      Serial.print("V - Charging: ");
      Serial.print(isBatteryCharging ? "Yes" : "No");
      Serial.print(" - Standby: ");
      Serial.println(isBatteryStandBy ? "Yes" : "No");
      
      // If connected, update BLE Joystick battery level
      if (joystick->getState() == BLEJoystick::DEVICE_CONNECTED) {
        joystick->setBatteryLevel(batteryLevel);
        joystick->notifyBatteryLevel();
      }
    }  
    lastBatteryCheck = millis(); 
  }

  // Check if battery level is low
  if (batteryLevel < 20) {
    digitalWrite(RED_LED_PIN, (currentTime / 500) % 2 == 0);
  } else {
    digitalWrite(RED_LED_PIN, HIGH); // Turn off red LED
  }

  // Check battery charging status and update GREEN LED

  if (isBatteryCharging && !isBatteryStandBy) {
    // Blinking green LED when charging (toggle every 500ms)
    digitalWrite(GREEN_LED_PIN, (currentTime / 500) % 2 == 0);
  } else if (isBatteryStandBy) {
    // Solid green LED when fully charged
    digitalWrite(GREEN_LED_PIN, LOW); // LED is active LOW
  } else {
    // No charging activity - LED off
    digitalWrite(GREEN_LED_PIN, HIGH); // LED is active LOW
  }

  // Check for connection inactivity - put device to sleep
  if (joystick->getState() == BLEJoystick::DEVICE_IDLE
      && !isExternalPower
      && currentTime - idleStartTime > CONNECTION_IDLE_TIMEOUT) {
    Serial.println("Connection timeout, going to sleep...");
    enterSleepMode();
  } else if (isExternalPower) {
    // Reset idle timer if charging
    idleStartTime = currentTime;
  }

  // Check for inactivity - put device to sleep if no button press 
  if (currentTime - nesController->getLastActivityTime() > IDLE_TIMEOUT
      && !isExternalPower) {
    Serial.println("No button activity, going to sleep...");
    enterSleepMode();
  } else if (isExternalPower) {
    // Reset timer if charging
    nesController->resetLastActivityTime();
  }
  
  // Check if device is advertising for too long
  if (joystick->getState() == BLEJoystick::DEVICE_ADVERTISING && 
      currentTime - advertisingStartTime > ADVERTISING_TIMEOUT) {
    Serial.println("Device advertising for too long, stopping...");
    joystick->stopAdvertising();
    digitalWrite(BLUE_LED_PIN, HIGH);
  } else if (joystick->getState() == BLEJoystick::DEVICE_ADVERTISING) {
    // Blink LED while advertising
    digitalWrite(BLUE_LED_PIN, (currentTime / 500) % 2 == 0);
  }

 // Check for start button long press (sleep)
  if (nesController->getButtonState(playerSelection, NESController::BUTTON_START)) {
    // Start button pressed or still being held
    if (startButtonPressTime == 0) {
      // Just pressed, record time
      startButtonPressTime = currentTime;
    } else if (currentTime - startButtonPressTime >= POWER_OFF_HOLD_TIME) {
      // Held for the required duration, sleep
      Serial.println("Start button held for 5 seconds, entering sleep mode ...");
      enterSleepMode();
    }
  } else {
    // Start button released
    startButtonPressTime = 0;
  }
  
  // Check for select button long press (disconnect and restart advertising)
  if (nesController->getButtonState(playerSelection, NESController::BUTTON_SELECT)) {
    // Select button pressed or still being held
    if (selectButtonPressTime == 0) {
      // Just pressed, record time
      selectButtonPressTime = currentTime;
    } else if (currentTime - selectButtonPressTime >= RECONNECT_HOLD_TIME) {
      // Held for the required duration, disconnect and start advertising
      Serial.println("Select button held for 5 seconds, disconnecting ...");
      
      // Only perform the action once when threshold is reached
      selectButtonPressTime = 0;
    
      // If connected, disconnect first
      if (joystick->getState() == BLEJoystick::DEVICE_CONNECTED) {
        joystick->disconnect();
      } else {
        // Stop any current advertising
        joystick->stopAdvertising();
      }
    }
  } else {
    // Select button released
    selectButtonPressTime = 0;
  }
  
  // Check for profile change combination (A + B + Up held for 5 seconds)
  if (nesController->getButtonState(playerSelection, NESController::BUTTON_A) &&
      nesController->getButtonState(playerSelection, NESController::BUTTON_B) &&
      nesController->getButtonState(playerSelection, NESController::BUTTON_UP)) {
    // Profile change combination pressed or still being held
    if (profileChangeStartTime == 0) {
      // Just pressed, record time
      profileChangeStartTime = currentTime;
    } else if (currentTime - profileChangeStartTime >= PROFILE_CHANGE_HOLD_TIME) {
      // Held for the required duration, change profile
      Serial.println("A+B+Up held for 5 seconds, changing profile...");
      changeProfile();
      
      // Only perform the action once when threshold is reached
      profileChangeStartTime = 0;
    }
  } else {
    // Profile change combination released
    profileChangeStartTime = 0;
  }
  
  // Check for directional mode change combination (Down + A + B held for 5 seconds)
  if (nesController->getButtonState(playerSelection, NESController::BUTTON_DOWN) &&
      nesController->getButtonState(playerSelection, NESController::BUTTON_A) &&
      nesController->getButtonState(playerSelection, NESController::BUTTON_B)) {
    // Directional mode change combination pressed or still being held
    if (dpadModeChangeStartTime == 0) {
      // Just pressed, record time
      dpadModeChangeStartTime = currentTime;
    } else if (currentTime - dpadModeChangeStartTime >= DPAD_MODE_CHANGE_HOLD_TIME) {
      // Held for the required duration, change directional mode
      Serial.println("Down+A+B held for 5 seconds, changing directional mode...");
      changeDirectionalMode();
      
      // Only perform the action once when threshold is reached
      dpadModeChangeStartTime = 0;
    }
  } else {
    // Directional mode change combination released
    dpadModeChangeStartTime = 0;
  }
}

bool readBatteryState() {
  bool wasCharging = isBatteryCharging;
  bool wasFullyCharged = isBatteryStandBy;
  isBatteryCharging = digitalRead(BATTERY_CHARGE_PIN) == LOW;
  isBatteryStandBy = digitalRead(BATTERY_STANDBY_PIN) == LOW;
  isExternalPower = isBatteryCharging || isBatteryStandBy;
  // If charging state changed, reset smoothed voltage
  if (wasCharging != isBatteryCharging || wasFullyCharged != isBatteryStandBy)
  {
    smoothedBatteryVoltage = 0.0; // Reset smoothed voltage when charging state changes
  }
  
  // Read raw ADC value and convert to voltage
  float currentVoltage = (analogRead(BATTERY_PIN) / 4095.0) * 3.3;
  currentVoltage = (currentVoltage * (BATTERY_VOLTAGE_DIVIDER_R1 + BATTERY_VOLTAGE_DIVIDER_R2)) / BATTERY_VOLTAGE_DIVIDER_R2;
  currentVoltage *= BATTERY_VOLTAGE_CALIBRATION_FACTOR;
  
  // Apply exponential moving average filter for smoothing
  if (smoothedBatteryVoltage == 0.0) {
    // First reading or after reset
    smoothedBatteryVoltage = currentVoltage;
  } else {
    // Apply EMA filter: smoothed = (1-alpha) * smoothed + alpha * current
    smoothedBatteryVoltage = (1 - BATTERY_SMOOTHING_FACTOR) * smoothedBatteryVoltage + 
                            BATTERY_SMOOTHING_FACTOR * currentVoltage;
  }
  
  // Update the global voltage variable with the smoothed value
  batteryVoltage = smoothedBatteryVoltage;
  
  // Calculate percentage based on smoothed voltage
  unsigned int prevBatteryLevel = batteryLevel;
  batteryLevel = (unsigned int)(((smoothedBatteryVoltage - BATTERY_MIN_VOLTAGE) / 
                         (BATTERY_MAX_VOLTAGE - BATTERY_MIN_VOLTAGE)) * 100.0);
  if (batteryLevel > 100) batteryLevel = 100;

  return wasCharging != isBatteryCharging || 
         wasFullyCharged != isBatteryStandBy || 
         prevBatteryLevel != batteryLevel;
}

void enterSleepMode() {
  Serial.flush();
  digitalWrite(RED_LED_PIN, HIGH);
  digitalWrite(GREEN_LED_PIN, HIGH);
  digitalWrite(BLUE_LED_PIN, HIGH);
  sleeping = true;
  esp_sleep_enable_timer_wakeup(SLEEP_CYCLE_TIME);
  esp_deep_sleep_start();
}

void loadProfile() {
  currentProfile = preferences.getUChar("profile", 0);
  if (currentProfile >= NUM_PROFILES) {
    currentProfile = 0; // Default to first profile if invalid
  }
  
  Serial.print("Loaded profile: ");
  Serial.print(currentProfile + 1);
  Serial.print(" (");
  Serial.print(profiles[currentProfile].name);
  Serial.println(")");
}

void saveProfile() {
  preferences.putUChar("profile", currentProfile);
  Serial.print("Saved profile: ");
  Serial.print(currentProfile + 1);
  Serial.print(" (");
  Serial.print(profiles[currentProfile].name);
  Serial.println(")");
}

void changeProfile() {
  currentProfile = (currentProfile + 1) % NUM_PROFILES;
  saveProfile();
  
  Serial.print("Changed to profile: ");
  Serial.print(currentProfile + 1);
  Serial.print(" (");
  Serial.print(profiles[currentProfile].name);
  Serial.println(")");
  
  // Blink LED to indicate new profile
  blinkIndicator(RED_LED_PIN, currentProfile + 1);
}

void blinkIndicator(uint8_t pin, uint8_t count) {
  // Turn LED first
  digitalWrite(pin, HIGH);
  
  delay(500); // Initial pause
  
  // Blink LED the number of times corresponding to the profile
  for (uint8_t i = 0; i < count; i++) {
    digitalWrite(pin, LOW);  // Turn on LED (active low)
    delay(300);
    digitalWrite(pin, HIGH); // Turn off LED
    delay(300);
  }
  
  delay(500); // Final pause
}

void updateJoystickButtons(uint8_t player) {
  // Get current profile
  const ButtonProfile& profile = profiles[currentProfile];
  
  // Create button array (12 buttons total)
  bool buttons[12] = {false};
  
  // Map NES buttons to joystick buttons based on current profile
  buttons[profile.buttonA - 1] = nesController->getButtonState(player, NESController::BUTTON_A);
  buttons[profile.buttonB - 1] = nesController->getButtonState(player, NESController::BUTTON_B);
  buttons[profile.buttonSelect - 1] = nesController->getButtonState(player, NESController::BUTTON_SELECT);
  buttons[profile.buttonStart - 1] = nesController->getButtonState(player, NESController::BUTTON_START);
  
  // Set all buttons at once for the specific player
  joystick->setPlayerButtons(player,
    buttons[0], buttons[1], buttons[2], buttons[3],
    buttons[4], buttons[5], buttons[6], buttons[7],
    buttons[8], buttons[9], buttons[10], buttons[11]
  );
}

void loadDirectionalMode() {
  uint8_t savedMode = preferences.getUChar("directionalMode", DPAD_ONLY);
  if (savedMode >= NUM_DIRECTIONAL_MODES) {
    savedMode = DPAD_ONLY; // Default to dpad only if invalid
  }
  currentDirectionalMode = (DirectionalMode)savedMode;
  
  Serial.print("Loaded directional mode: ");
  Serial.print((uint8_t)currentDirectionalMode + 1);
  Serial.print(" (");
  Serial.print(directionalModeNames[currentDirectionalMode]);
  Serial.println(")");
}

void saveDirectionalMode() {
  preferences.putUChar("directionalMode", (uint8_t)currentDirectionalMode);
  Serial.print("Saved directional mode: ");
  Serial.print((uint8_t)currentDirectionalMode + 1);
  Serial.print(" (");
  Serial.print(directionalModeNames[currentDirectionalMode]);
  Serial.println(")");
}

void changeDirectionalMode() {
  currentDirectionalMode = (DirectionalMode)(((uint8_t)currentDirectionalMode + 1) % NUM_DIRECTIONAL_MODES);
  saveDirectionalMode();
  
  Serial.print("Changed to directional mode: ");
  Serial.print((uint8_t)currentDirectionalMode + 1);
  Serial.print(" (");
  Serial.print(directionalModeNames[currentDirectionalMode]);
  Serial.println(")");
  
  // Blink LED to indicate new directional mode
  blinkIndicator(RED_LED_PIN, (uint8_t)currentDirectionalMode + 1);
}

void updateJoystickDirectional(uint8_t player) {
  // Get directional values from controller for the specific player
  uint8_t dpadDirection = nesController->getHatDirection(player);
  int8_t x = nesController->getXAxis(player);
  int8_t y = nesController->getYAxis(player);
  
  // Apply directional input based on current mode for the specific player
  switch (currentDirectionalMode) {
    case DPAD_ONLY:
      joystick->setPlayerHat(player, dpadDirection);
      joystick->setPlayerAxes(player, 0, 0, 0, 0, 0, 0, 0, 0); // Clear axes
      break;
      
    case AXES_ONLY:
      joystick->setPlayerHat(player, 0); // Clear hat/dpad
      joystick->setPlayerAxes(player, x, y, 0, 0, 0, 0, 0, 0);
      break;
      
    case BOTH:
      joystick->setPlayerHat(player, dpadDirection);
      joystick->setPlayerAxes(player, x, y, 0, 0, 0, 0, 0, 0);
      break;
  }
}

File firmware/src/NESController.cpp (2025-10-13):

#include "NESController.h"

NESController::NESController(uint8_t clkPin1, uint8_t clkPin2, uint8_t latchPin, uint8_t dataPin1, uint8_t dataPin2) 
    : _clkPin1(clkPin1), _clkPin2(clkPin2), _latchPin(latchPin), _dataPin1(dataPin1), _dataPin2(dataPin2), _playerSelection(0), _playerSelectionCallback(nullptr) {
    
    // Initialize button states
    for (int i = 0; i < 2; i++) {
        for (int j = 0; j < 8; j++) {
            _buttonState[i][j] = false;
            _prevButtonState[i][j] = false;
        }
        _stateChanged[i] = false;
    }
    
    _playerSelection = 0;
    _lastActivityTime = millis();
}

void NESController::begin() {
    // Configure NES controller pins
    pinMode(_clkPin1, OUTPUT);
    pinMode(_clkPin2, OUTPUT);
    pinMode(_latchPin, OUTPUT);
    pinMode(_dataPin1, INPUT_PULLUP);
    pinMode(_dataPin2, INPUT_PULLUP);
}

void NESController::read() {
    // Reset state change flags
    _stateChanged[0] = false;
    _stateChanged[1] = false;
    
    // Latch current button states
    digitalWrite(_latchPin, HIGH);
    delayMicroseconds(12);  // Latch pulse (min 12µs)
    digitalWrite(_latchPin, LOW);
    
    // Read all 8 buttons
    for (int i = 0; i < 8; i++) {
        // NES buttons are active low, so invert the reading
        _buttonState[0][i] = !digitalRead(_dataPin1);
        _buttonState[1][i] = !digitalRead(_dataPin2);
        
        // Clock pulse
        digitalWrite(_clkPin1, HIGH);
        digitalWrite(_clkPin2, HIGH);
        delayMicroseconds(6);
        digitalWrite(_clkPin1, LOW);
        digitalWrite(_clkPin2, LOW);
        delayMicroseconds(6);
    }

    // Check if state has changed
    for (int i = 0; i < 8; i++) {
        if (_buttonState[0][i] != _prevButtonState[0][i]) {
            _stateChanged[0] = true;
            _prevButtonState[0][i] = _buttonState[0][i];
        }
        if (_buttonState[1][i] != _prevButtonState[1][i]) {
            _stateChanged[1] = true;
            _prevButtonState[1][i] = _buttonState[1][i];
        }
    }

    // Update player selection based on button state
    // When all buttons are pressed we assume the player is not selected
    uint8_t previousPlayerSelection = _playerSelection;
    
    if (_allTrue(_buttonState[0], 8) && _playerSelection != 1) {
        _playerSelection = 1; // P2 selected
    } else if (_allTrue(_buttonState[1], 8) && _playerSelection != 0) {
        _playerSelection = 0; // P1 selected
    }
    
    // Call the callback if player selection changed and callback is set
    if (_playerSelection != previousPlayerSelection) {
        // wait a little to debounce the selection change
        delay(100);
        if (_playerSelectionCallback != nullptr) {
            _playerSelectionCallback(_playerSelection);
        }
    }
    
    // Update last activity time if state changed
    if (_stateChanged[0] || _stateChanged[1]) {
        _lastActivityTime = millis();
    }
}

bool NESController::stateChanged(uint8_t player) {
    return (player < 2) ? _stateChanged[player] : false;
}

bool NESController::getButtonState(uint8_t player, uint8_t button) {
    return (player < 2 && button < 8) ? _buttonState[player][button] : false;
}

uint8_t NESController::getPlayerSelection() {
    return _playerSelection;
}

void NESController::setPlayerSelectionCallback(PlayerSelectionCallback callback) {
    _playerSelectionCallback = callback;
}

unsigned long NESController::getLastActivityTime() {
    return _lastActivityTime;
}

void NESController::resetLastActivityTime() {
    _lastActivityTime = millis();
}

uint8_t NESController::getHatDirection(uint8_t player) {
    if (player >= 2) return 0;
    
    uint8_t dpadDirection = 0;
    if (_buttonState[player][BUTTON_UP] && _buttonState[player][BUTTON_RIGHT]) {
        dpadDirection = 2;
    } else if (_buttonState[player][BUTTON_RIGHT] && _buttonState[player][BUTTON_DOWN]) {
        dpadDirection = 4;
    } else if (_buttonState[player][BUTTON_DOWN] && _buttonState[player][BUTTON_LEFT]) {
        dpadDirection = 6;
    } else if (_buttonState[player][BUTTON_LEFT] && _buttonState[player][BUTTON_UP]) {
        dpadDirection = 8;
    } else if (_buttonState[player][BUTTON_UP]) {
        dpadDirection = 1;
    } else if (_buttonState[player][BUTTON_RIGHT]) {
        dpadDirection = 3;
    } else if (_buttonState[player][BUTTON_DOWN]) {
        dpadDirection = 5;
    } else if (_buttonState[player][BUTTON_LEFT]) {
        dpadDirection = 7;
    } else {
        dpadDirection = 0;
    }
    
    return dpadDirection;
}

int8_t NESController::getXAxis(uint8_t player) {
    if (player >= 2) return 0;
    return _buttonState[player][BUTTON_RIGHT] ? 127 : (_buttonState[player][BUTTON_LEFT] ? -127 : 0);
}

int8_t NESController::getYAxis(uint8_t player) {
    if (player >= 2) return 0;
    return _buttonState[player][BUTTON_DOWN] ? 127 : (_buttonState[player][BUTTON_UP] ? -127 : 0);
}

bool NESController::_allTrue(bool array[], int size) {
    for (int i = 0; i < size; i++) {
        if (!array[i]) return false;
    }
    return true;
}

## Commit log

2025-04-23 Added early version of firmware. pcb, and model
    [bt-nes-advantage.FCStd, bt-nes-advantage.kicad_pcb, bt-nes-advantage.kicad_sch]
2025-05-12 Added hold start to power off and select to disconnect features.
2025-05-23 New PCB revision. Updated firmware logic.
    [bt-nes-advantage.kicad_pcb, bt-nes-advantage.kicad_sch, bt-nes-advantage.step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]
2025-06-12 pcb update
    [bt-nes-advantage.kicad_pcb, bt-nes-advantage.kicad_sch, bt-nes-advantage.step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]
2025-06-13 Refactor battery management and LED indicators; implement sleep mode functionality
2025-06-15 Refactor code structure for improved readability and maintainability
    [bt-nes-advantage.FCStd]
2025-06-15 Add PCB sourcing link to README for parts procurement
2025-06-15 Update J2 Connector Harness Cable link in parts list
2025-06-15 Added custopm font used on PCB and PCB images
2025-06-15 Removed unused file.
    [bt-nes-advantage_old.kicad_sch]
2025-06-21 Add NESController class for handling NES controller input
    - Implemented NESController class with methods for reading button states, checking state changes, and managing player selection.
    - Added support for two players with separate button states and selection callbacks.
    - Included methods to retrieve button states, axis values, and hat direction.
    - Initialized controller pins and set up input handling in the constructor and begin method.
    - Implemented debouncing for player selection changes.
    [bt-nes-advantage.kicad_sch]
2025-06-21 Update pin mapping image to reflect recent changes
2025-06-21 Update pin mapping SVG attachment
2025-06-22 Add battery state management and reset functionality to NESController
    [NESController.cpp, main.cpp]
2025-06-27 Fixed bug where controller owuld go to sleep after fully charged even when still plugged in.
    [main.cpp]
2025-06-27 Added gerber link
2025-07-13 Added silkscreen labels for the LED indicators.
    [bt-nes-advantage.kicad_pcb]
2025-07-13 Update PCB design file for BT NES Advantage
2025-07-17 Add button profile mapping feature. Added dpad mode feature. Updated pcb silkscreen to help with assembly. Updated README with assembly tips.
    [bt-nes-advantage.kicad_pcb]
2025-07-23 Updated PCB shape to clear the back panel wedge on some versions of the NES Advantage,
    [bt-nes-advantage.kicad_pcb]
2025-10-13 Added missing ground trace for battery voltage detection.
    [bt-nes-advantage.kicad_pcb]
2025-10-13 Updated board revision.
    [bt-nes-advantage.kicad_pcb]

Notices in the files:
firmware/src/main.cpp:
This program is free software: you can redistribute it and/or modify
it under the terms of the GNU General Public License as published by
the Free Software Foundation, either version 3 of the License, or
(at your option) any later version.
